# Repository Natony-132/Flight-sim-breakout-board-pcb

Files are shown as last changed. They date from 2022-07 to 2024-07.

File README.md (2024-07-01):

# Flight simulator control integration PCB 

This project was to make a simple, expandable, Hardware to USB input control board. This is so that additional, non-standard controls or switch panels can be added to an existing flight simulator setup. 

This was accomplished by using an existing Arduino program called FreeJoy with a custom Interface board. The freeJoy program allows a series of Shift registers to expand the number of inputs that an arduino can normally except. 

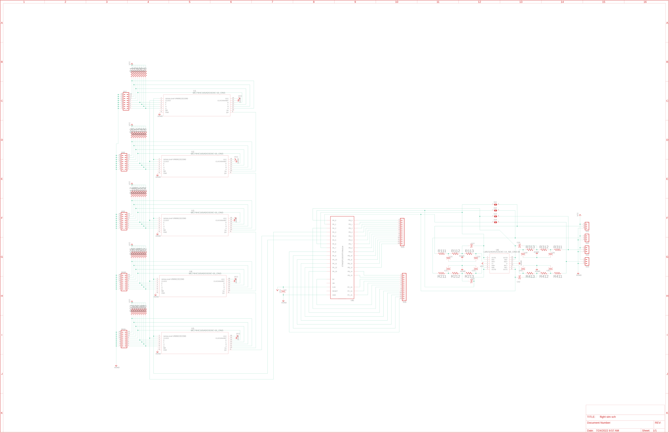
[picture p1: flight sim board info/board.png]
PCB layout
 

This custom PCB was designed with 40 inputs for switches and pads for up to 4 potentiometers.  

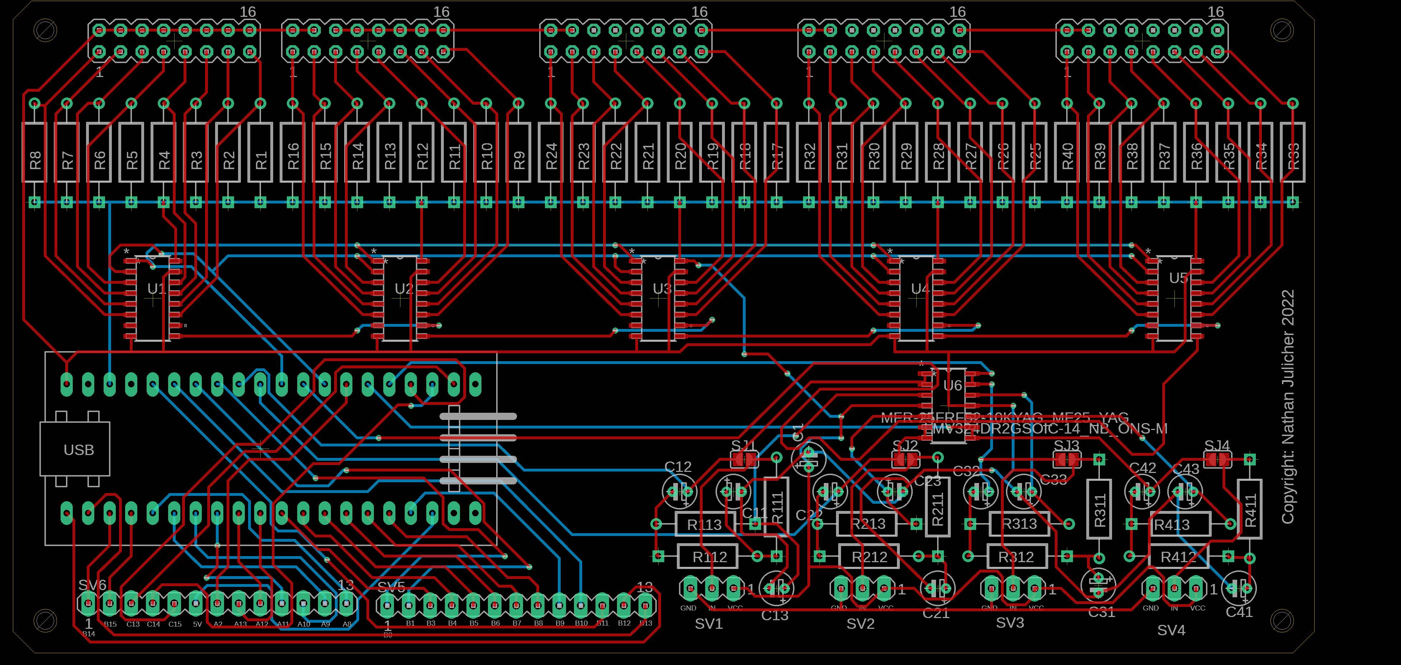
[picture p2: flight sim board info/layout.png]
other PCB layout
 

Due to signal noise in most potentiometers, each pad was designed to have a 3rd order filter built in. 

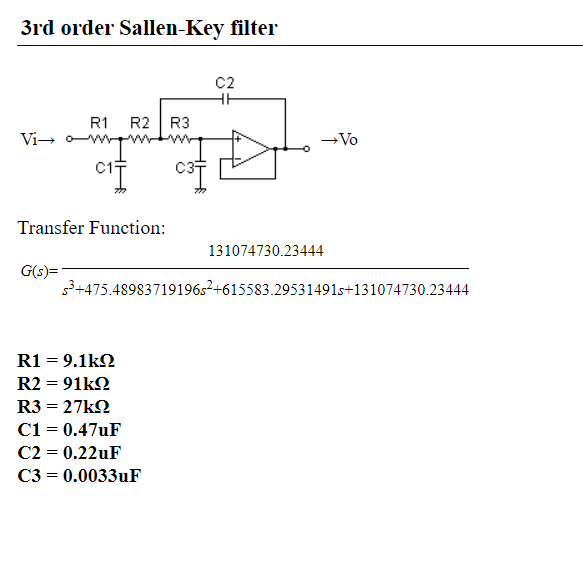
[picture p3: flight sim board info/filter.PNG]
3rd order filter
 

This proved to be unnecessary due to filters built into the Arduino program. This was not unexpected, so a filter bypass was built into the PCB so that the physical filter doesn't need to not be populated during board assembly. 

Later iterations will leave off this filter entirely.

These custom circuit boards were used in a UH-34 Sikorsky helicopter collective and a replica FA18 landing gear panel. 
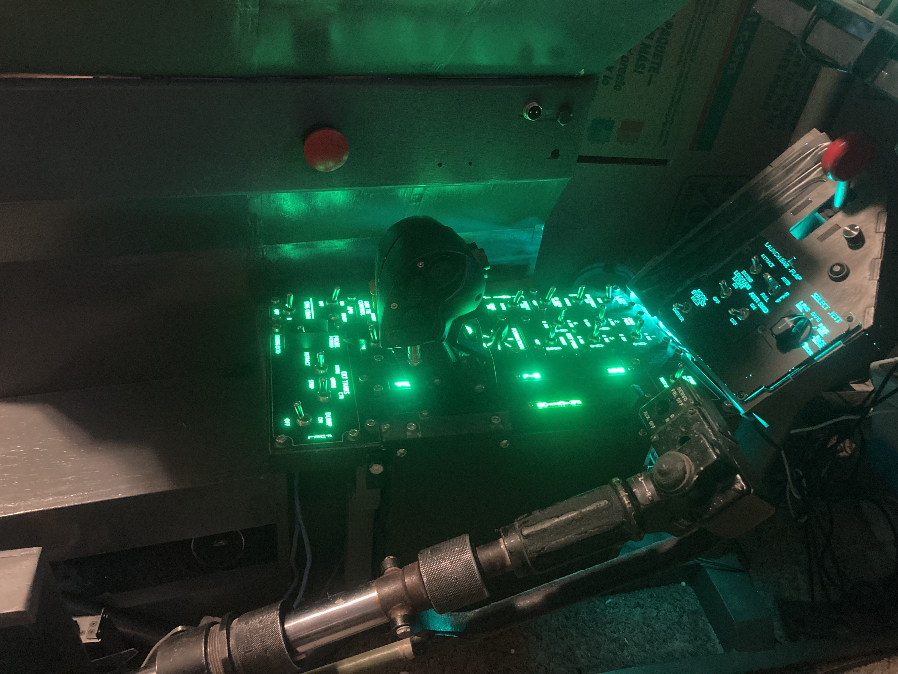
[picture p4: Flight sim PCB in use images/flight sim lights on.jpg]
PCB in use

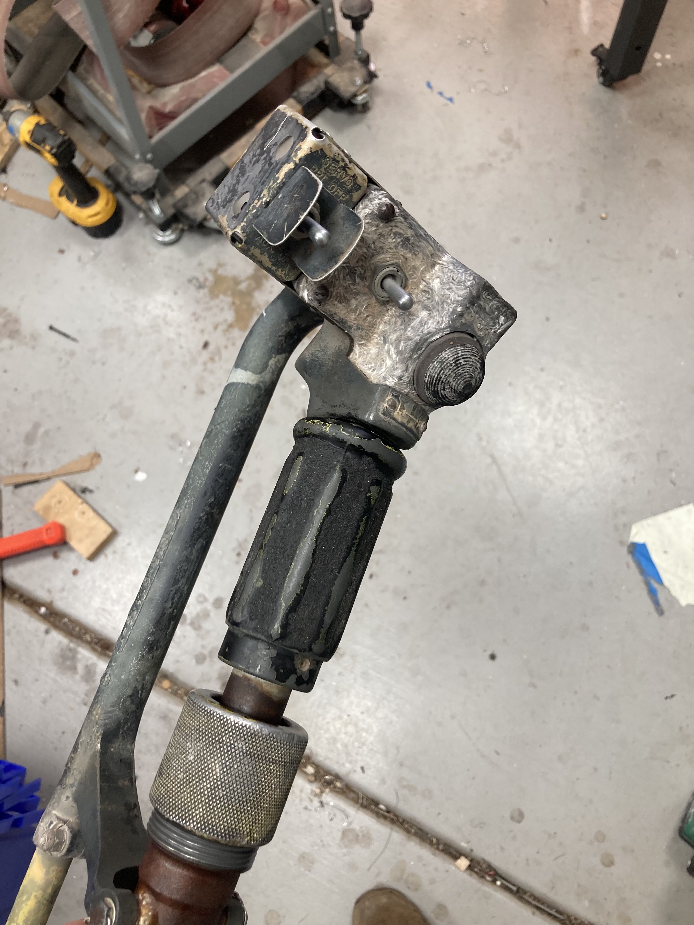
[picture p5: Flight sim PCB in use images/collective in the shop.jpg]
PCB demo

Flight sim in progress
PCB in use 1.5
PCB in use 2

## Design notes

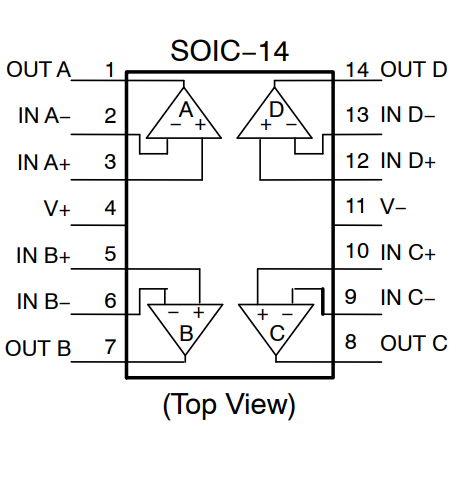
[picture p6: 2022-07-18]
flight sim board info/opamp.png

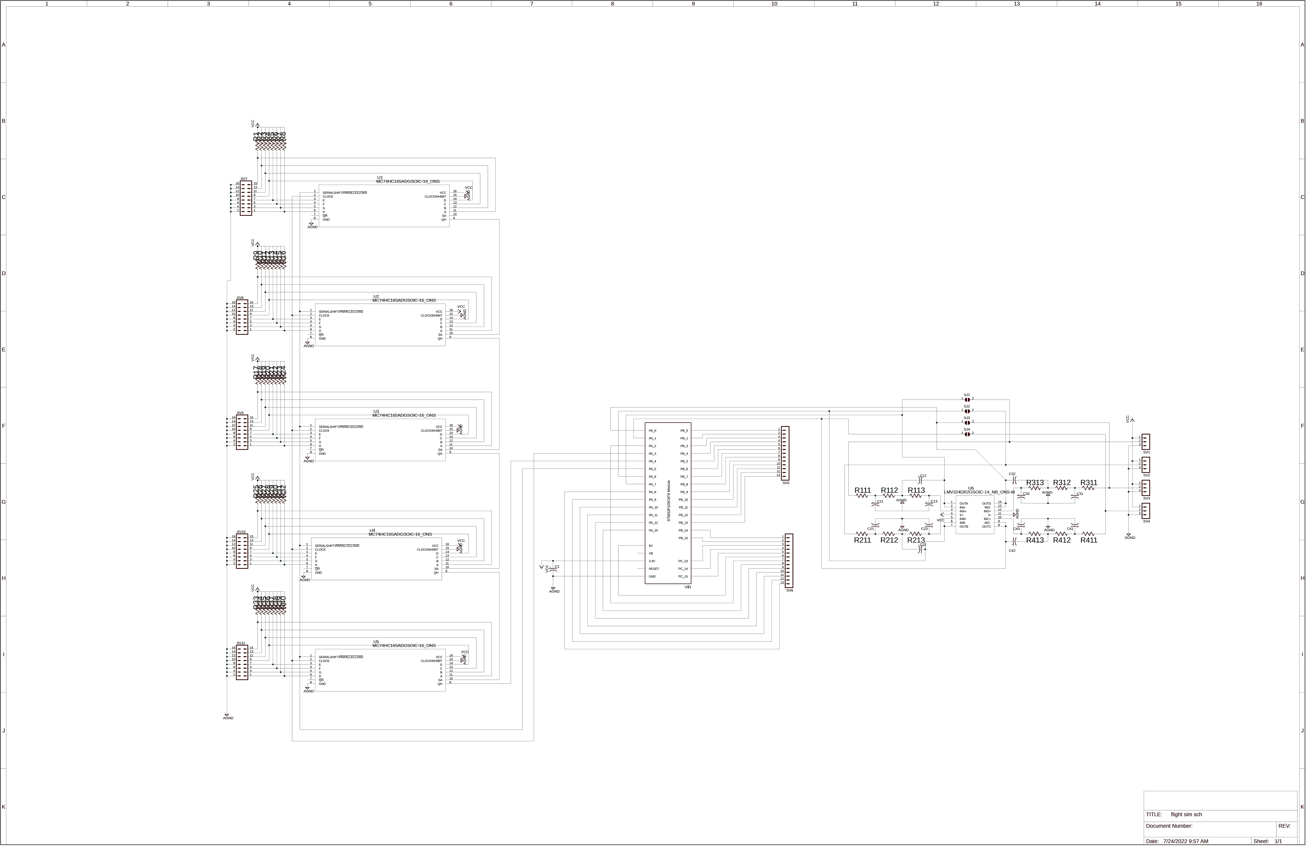
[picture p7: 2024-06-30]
flight sim board info/board2.png

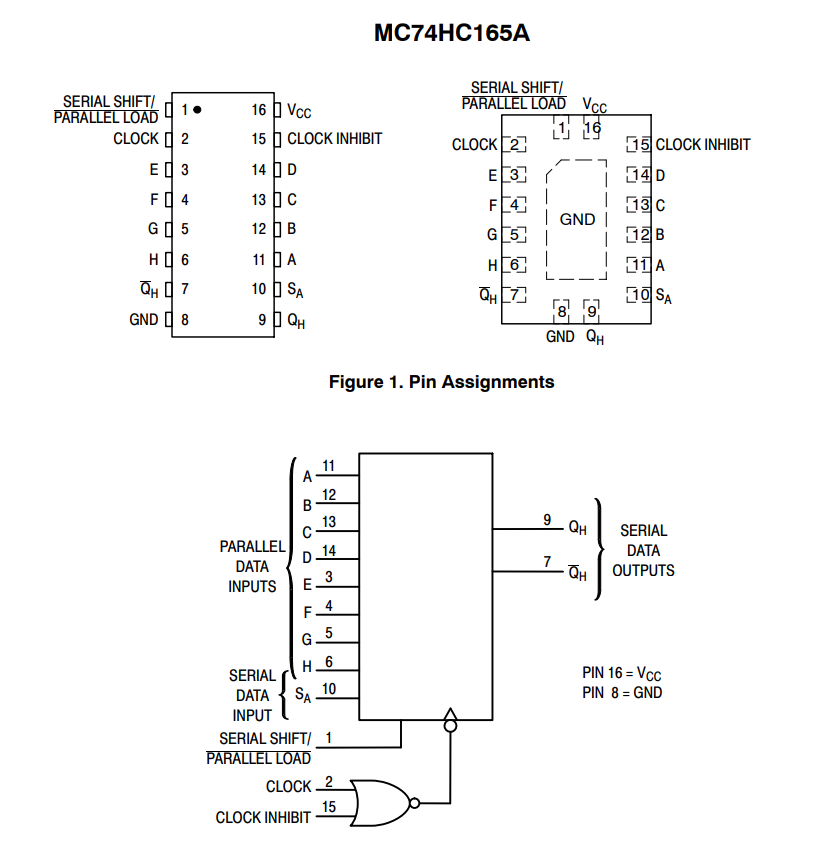
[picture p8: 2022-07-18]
flight sim board info/shift_pic.png

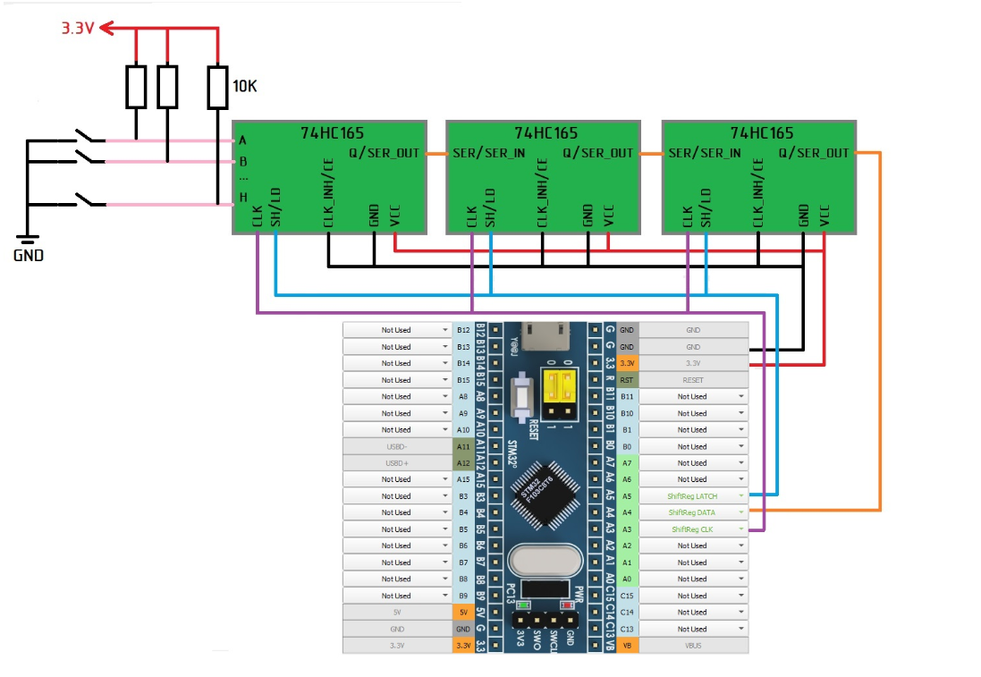
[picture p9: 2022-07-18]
flight sim board info/shift.PNG

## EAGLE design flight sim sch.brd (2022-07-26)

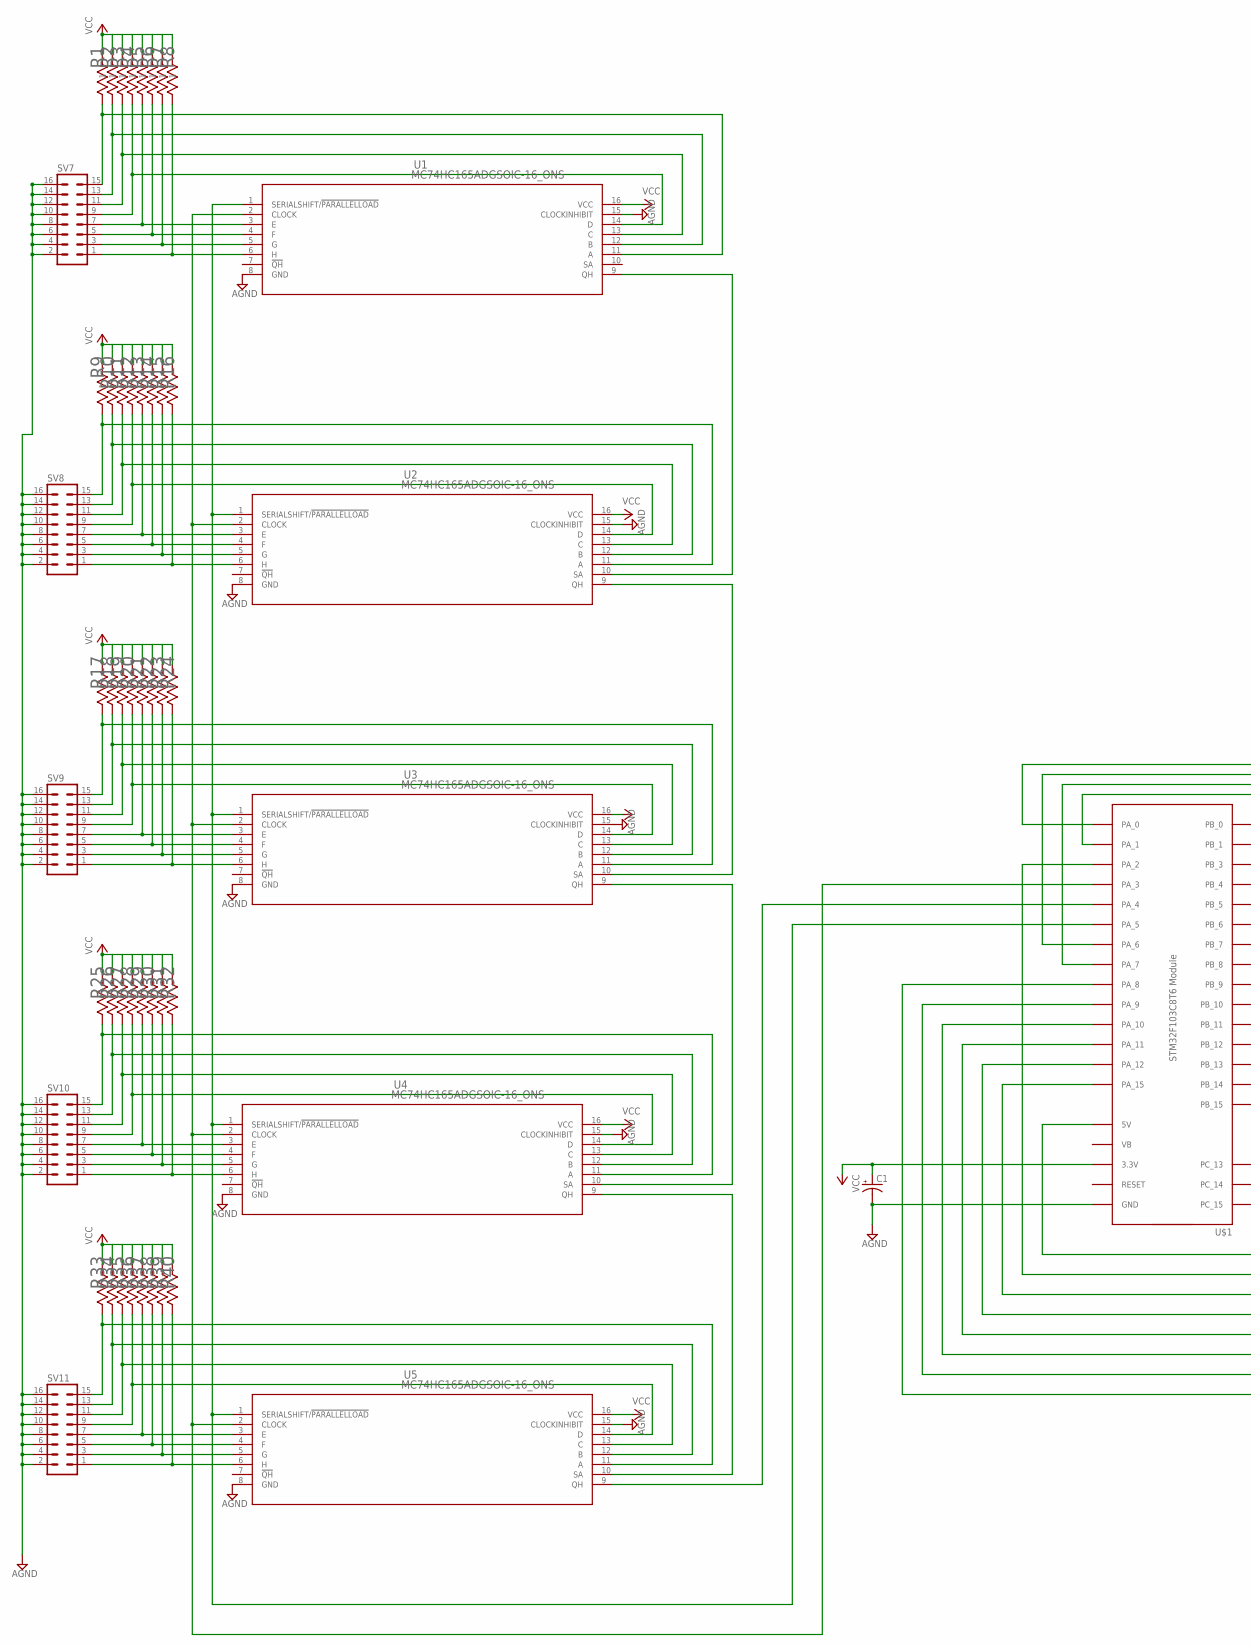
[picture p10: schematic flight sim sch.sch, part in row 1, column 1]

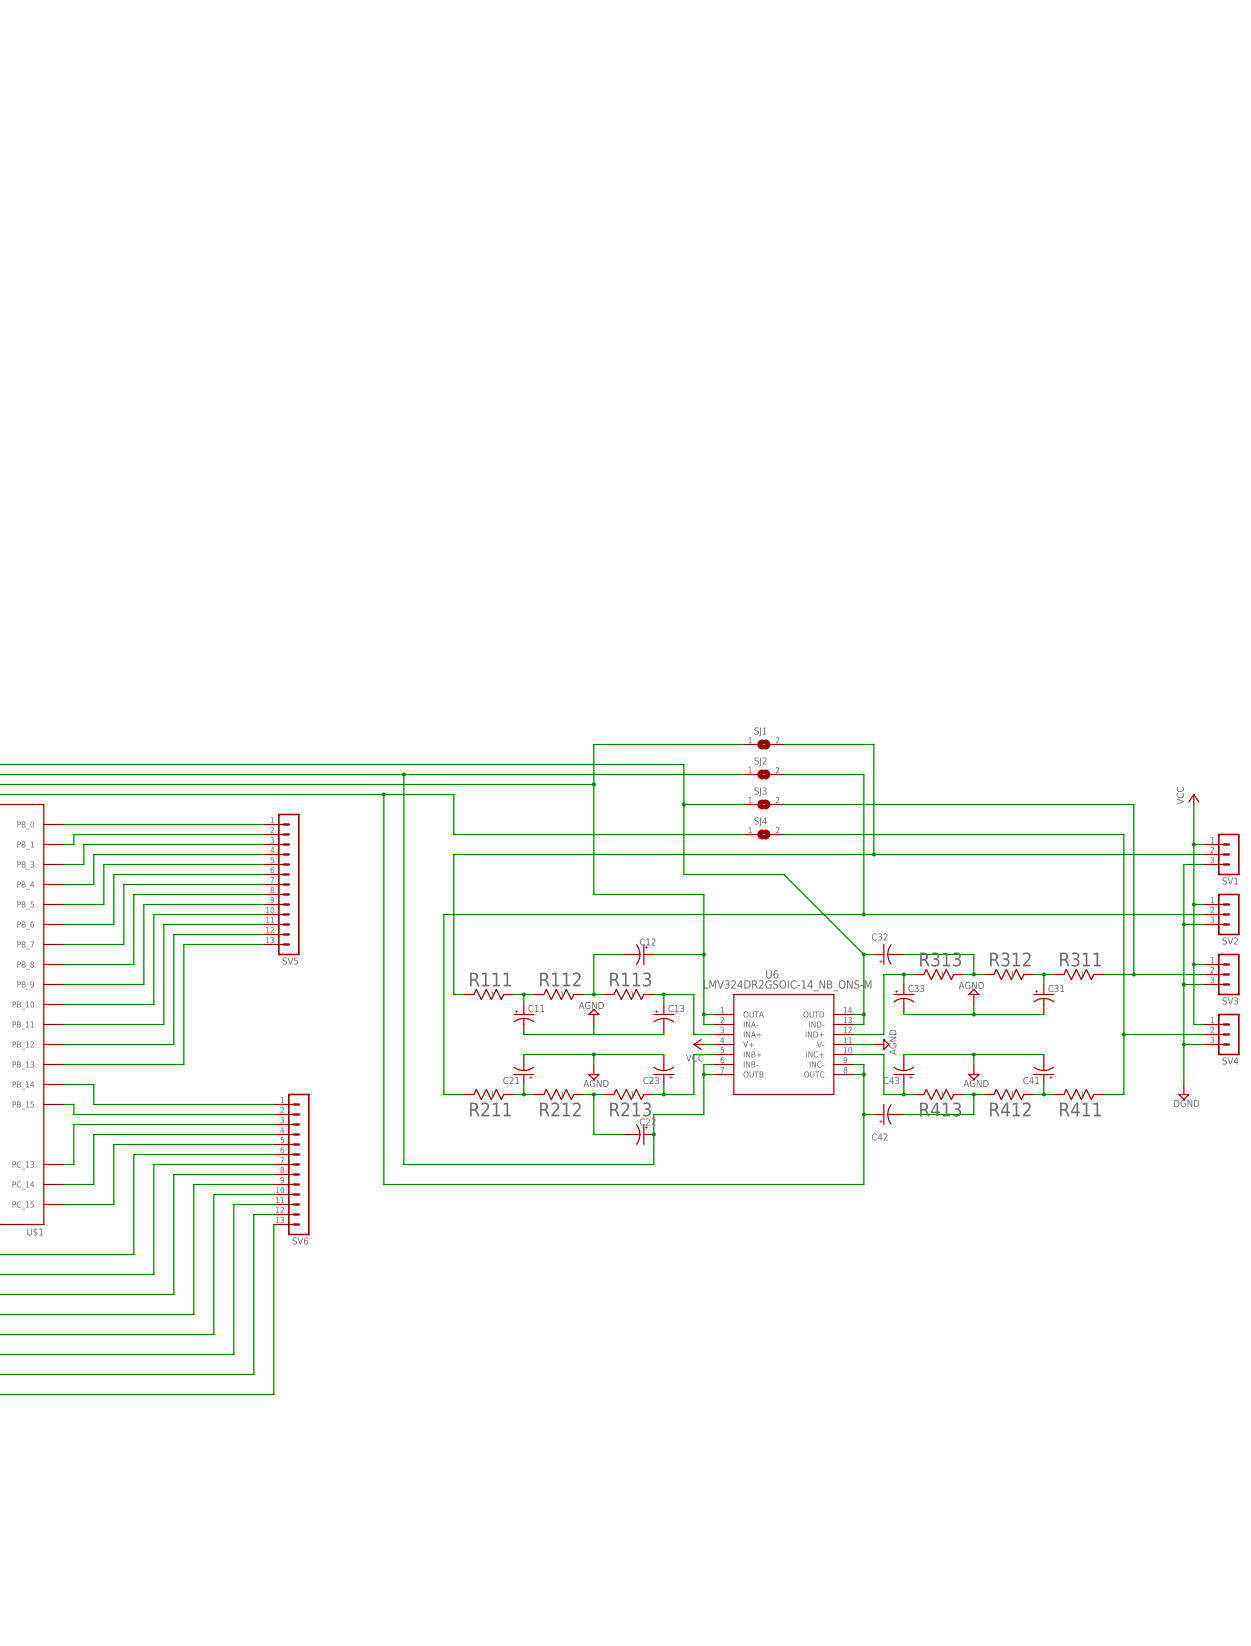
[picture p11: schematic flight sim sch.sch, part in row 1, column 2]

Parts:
C1, C11, C12, C13, C21, C22, C23, C31, C32, C33, C41, C42, C43: CPOL-USE1.8-4; E1,8-4
R1, R2, R3, R4, R5, R6, R7, R8, R9, R10, R11, R12, R13, R14, R15, R16, R17, R18, R19, R20, R21, R22, R23, R24, R25, R26, R27, R28, R29, R30, R31, R32, R33, R34, R35, R36, R37, R38, R39, R40, R111, R112, R113, R211, R212, R213, R311, R312, R313, R411, R412, R413: MFR-25FRF52-10KYAG_MF25_YAG; YAG_MF25_YAG
SJ1, SJ2, SJ3, SJ4: SJ
SV1, SV2, SV3, SV4: MA03-1
SV5, SV6: MA13-1
SV7, SV8, SV9, SV10, SV11: MA08-2
U1, U2, U3, U4, U5: MC74HC165ADGSOIC-16_ONS; SOIC-16_ONS
U6: LMV324DR2GSOIC-14_NB_ONS-M; SOIC-14_NB_ONS-M
U$1: STM32F103C8T6-MODULE

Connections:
AGND: C1.-, C11.-, C13.-, C21.-, C23.-, C31.-, C33.-, C41.-, C43.-, SV7.2, SV7.4, SV7.6, SV7.8, SV7.10, SV7.12, SV7.14, SV7.16, SV8.2, SV8.4, SV8.6, SV8.8, SV8.10, SV8.12, SV8.14, SV8.16, SV9.2, SV9.4, SV9.6, SV9.8, SV9.10, SV9.12, SV9.14, SV9.16, SV10.2, SV10.4, SV10.6, SV10.8, SV10.10, SV10.12, SV10.14, SV10.16, SV11.2, SV11.4, SV11.6, SV11.8, SV11.10, SV11.12, SV11.14, SV11.16, U1.8 (GND), U1.15 (CLOCKINHIBIT), U2.8 (GND), U2.15 (CLOCKINHIBIT), U3.8 (GND), U3.15 (CLOCKINHIBIT), U4.8 (GND), U4.15 (CLOCKINHIBIT), U5.8 (GND), U5.15 (CLOCKINHIBIT), U6.11 (V-), U$1.GND@1 (GND), U$1.GND@2 (GND), U$1.GND@3 (GND)
DGND: SV1.3, SV2.3, SV3.3, SV4.3
unnamed: U1.9 (QH), U2.10 (SA)
unnamed: R8.2, SV7.1, U1.6 (H)
unnamed: R7.2, SV7.3, U1.5 (G)
unnamed: R6.2, SV7.5, U1.4 (F)
unnamed: R5.2, SV7.7, U1.3 (E)
unnamed: R4.2, SV7.9, U1.14 (D)
unnamed: R3.2, SV7.11, U1.13 (C)
unnamed: R2.2, SV7.13, U1.12 (B)
unnamed: R1.2, SV7.15, U1.11 (A)
unnamed: U1.2 (CLOCK), U2.2 (CLOCK), U3.2 (CLOCK), U4.2 (CLOCK), U5.2 (CLOCK), U$1.PA_3
unnamed: R16.2, SV8.1, U2.6 (H)
unnamed: R15.2, SV8.3, U2.5 (G)
unnamed: R14.2, SV8.5, U2.4 (F)
unnamed: R13.2, SV8.7, U2.3 (E)
unnamed: R24.2, SV9.1, U3.6 (H)
unnamed: R23.2, SV9.3, U3.5 (G)
unnamed: R22.2, SV9.5, U3.4 (F)
unnamed: R21.2, SV9.7, U3.3 (E)
unnamed: R20.2, SV9.9, U3.14 (D)
unnamed: R19.2, SV9.11, U3.13 (C)
unnamed: R18.2, SV9.13, U3.12 (B)
unnamed: R12.2, SV8.9, U2.14 (D)
unnamed: R32.2, SV10.1, U4.6 (H)
unnamed: R31.2, SV10.3, U4.5 (G)
unnamed: R30.2, SV10.5, U4.4 (F)
unnamed: R29.2, SV10.7, U4.3 (E)
unnamed: R28.2, SV10.9, U4.14 (D)
unnamed: R27.2, SV10.11, U4.13 (C)
unnamed: R26.2, SV10.13, U4.12 (B)
unnamed: R33.2, SV11.15, U5.11 (A)
unnamed: R25.2, SV10.15, U4.11 (A)
unnamed: R34.2, SV11.13, U5.12 (B)
unnamed: R11.2, SV8.11, U2.13 (C)
unnamed: R35.2, SV11.11, U5.13 (C)
unnamed: R36.2, SV11.9, U5.14 (D)
unnamed: R37.2, SV11.7, U5.3 (E)
unnamed: R38.2, SV11.5, U5.4 (F)
unnamed: R39.2, SV11.3, U5.5 (G)
unnamed: U2.9 (QH), U3.10 (SA)
unnamed: C11.+, R111.1, R112.2
unnamed: U3.9 (QH), U4.10 (SA)
unnamed: U4.9 (QH), U5.10 (SA)
unnamed: U5.9 (QH), U$1.PA_4
unnamed: U1.1 (SERIALSHIFT/!PARALLELLOAD), U2.1 (SERIALSHIFT/!PARALLELLOAD), U3.1 (SERIALSHIFT/!PARALLELLOAD), U4.1 (SERIALSHIFT/!PARALLELLOAD), U5.1 (SERIALSHIFT/!PARALLELLOAD), U$1.PA_5
unnamed: R40.2, SV11.1, U5.6 (H)
unnamed: C22.-, R212.1, R213.2
unnamed: C21.+, R211.1, R212.2
unnamed: C13.+, R113.1, U6.3 (INA+)
unnamed: C12.+, SJ1.1, U6.1 (OUTA), U6.2 (INA-), U$1.PA_7
unnamed: C12.-, R112.1, R113.2
unnamed: R10.2, SV8.13, U2.12 (B)
unnamed: R9.2, SV8.15, U2.11 (A)
unnamed: C42.-, R412.2, R413.1
unnamed: C23.+, R213.1, U6.5 (INB+)
unnamed: R17.2, SV9.15, U3.11 (A)
unnamed: C33.+, R313.2, U6.12 (IND+)
unnamed: C31.+, R311.2, R312.1
unnamed: C43.+, R413.2, U6.10 (INC+)
unnamed: C41.+, R411.2, R412.1
unnamed: C32.-, R312.2, R313.1
unnamed: SV6.7, U$1.PA_2
unnamed: SV6.6, U$1.5V
N$A8: SV6.13, U$1.PA_8
N$A9: SV6.12, U$1.PA_9
N$A10: SV6.11, U$1.PA_10
N$A11: SV6.10, U$1.PA_11
N$A12: SV6.9, U$1.PA_12
N$A15: SV6.8, U$1.PA_15
N$B0: SV5.1, U$1.PB_0
N$B1: SV5.2, U$1.PB_1
N$B3: SV5.3, U$1.PB_3
N$B4: SV5.4, U$1.PB_4
N$B5: SV5.5, U$1.PB_5
N$B6: SV5.6, U$1.PB_6
N$B7: SV5.7, U$1.PB_7
N$B8: SV5.8, U$1.PB_8
N$B9: SV5.9, U$1.PB_9
N$B10: SV5.10, U$1.PB_10
N$B11: SV5.11, U$1.PB_11
N$B12: SV5.12, U$1.PB_12
N$B13: SV5.13, U$1.PB_13
N$B14: SV6.1, U$1.PB_14
N$B15: SV6.2, U$1.PB_15
N$C13: SV6.3, U$1.PC_13
N$C14: SV6.4, U$1.PC_14
N$C15: SV6.5, U$1.PC_15
N$FILTER2OUT: C22.+, SJ2.1, U6.6 (INB-), U6.7 (OUTB), U$1.PA_6
N$FILTER3OUT: C32.+, SJ3.1, U6.13 (IND-), U6.14 (OUTD), U$1.PA_0
N$FILTER4OUT: C42.+, SJ4.1, U6.8 (OUTC), U6.9 (INC-), U$1.PA_1
N$POT1IN: R111.2, SJ1.2, SV1.2
N$POT2IN: R211.2, SJ2.2, SV2.2
N$POT3IN: R311.1, SJ3.2, SV3.2
N$POT4IN: R411.1, SJ4.2, SV4.2
VCC: C1.+, R1.1, R2.1, R3.1, R4.1, R5.1, R6.1, R7.1, R8.1, R9.1, R10.1, R11.1, R12.1, R13.1, R14.1, R15.1, R16.1, R17.1, R18.1, R19.1, R20.1, R21.1, R22.1, R23.1, R24.1, R25.1, R26.1, R27.1, R28.1, R29.1, R30.1, R31.1, R32.1, R33.1, R34.1, R35.1, R36.1, R37.1, R38.1, R39.1, R40.1, SV1.1, SV2.1, SV3.1, SV4.1, U1.16 (VCC), U2.16 (VCC), U3.16 (VCC), U4.16 (VCC), U5.16 (VCC), U6.4 (V+), U$1.3.3V@1 (3.3V), U$1.3.3V@2 (3.3V)

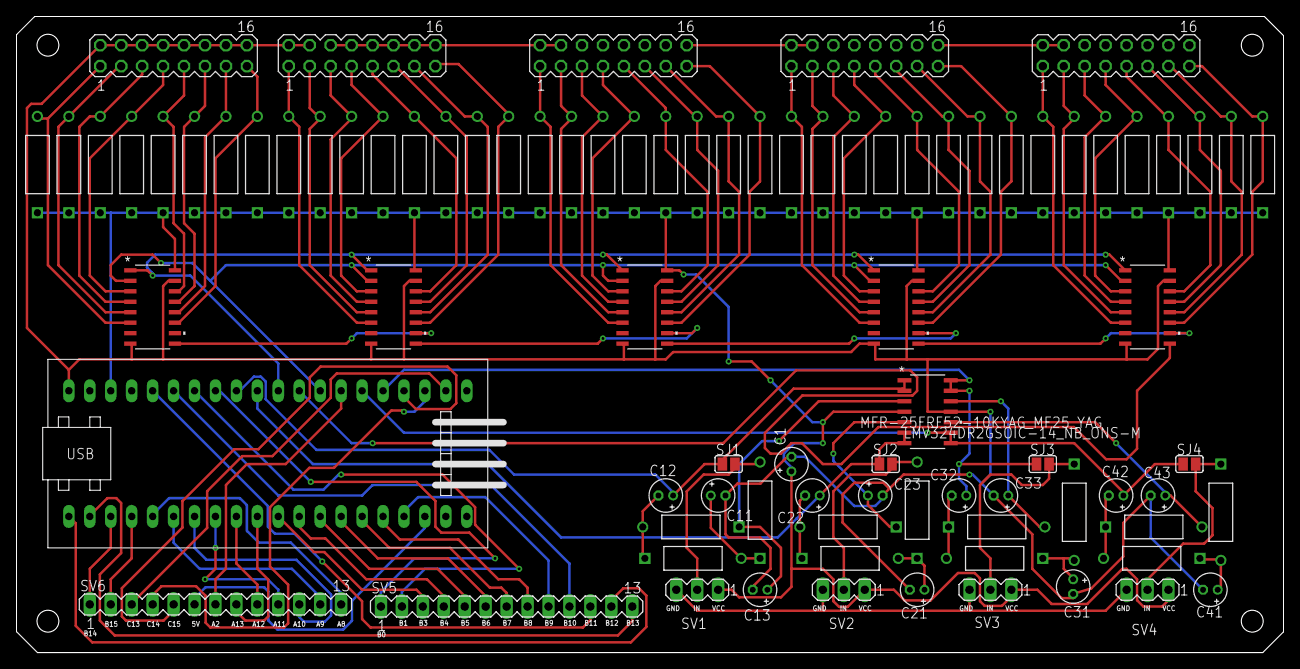
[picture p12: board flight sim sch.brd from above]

Board: 2 copper layers, 153.7 x 77.1 mm, 87 parts (0 on the bottom side), 96 nets.

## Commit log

2022-07-20 Create board
2022-07-21 trial layout ideas
    [flight sim sch.brd]
2024-07-01 Create Flight sim PCB in use

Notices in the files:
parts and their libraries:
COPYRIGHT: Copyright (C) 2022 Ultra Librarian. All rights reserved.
